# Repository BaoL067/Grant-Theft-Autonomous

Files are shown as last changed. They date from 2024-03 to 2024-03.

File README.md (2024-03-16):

# Grant Theft Autonomous 2023 
 This repository contains the source code for the annual competition of Design of Mechatronic Systems.

# TEAM 16, WE ARE THE CHAMPION !!!

# Video Link

- **Evaluation of functionality:** [**https://youtu.be/02jUuSZZPl0**](https://youtu.be/02jUuSZZPl0)

- **Final competition:** [**https://youtu.be/HylkRfzkrz0**](https://youtu.be/HylkRfzkrz0)

- **Compete Competition recording** at [GRASP Lab Youtube Channel.](https://www.youtube.com/watch?v=Pt5Qd4mry5I&t=9516s)



---



---

# Functionality

- Autonomous Wall Following
- Autonomous Beacon Tracking, Grasping Trophy
- Autonomous Navigate and Push the Police car
- Real-time positioning of XY location, and broadcasting via UDP
- Manual Wireless Control through Key-board

# Electrical Design

- ## Vive Localization System

  A single Vive chip can localize the position of robot, while two combined can determine the direction of it.

  ****

图片图片

- ## TOF Distance Measurement System

  Three TOF sensors are used in total, with two placed on the sides of the vehicle and one placed at the front.

  ****

  

- ## IR Beacon Tracking System

Two infrared sensors are placed at the front of the vehicle, each isolated with shading material, to increase detection range and enhance detection accuracy.

****

图片图片

- ## Motor Driver System

  

  

# BOM

| **Item** | **Quantities** | **Price** |
| --- | --- | --- |
| DC Motors | 2 | $68.0 |
| Wheels | 2 | $7.50 |
| ToF sensors | 6 | $17.0 |
| Claw | 1 | $18.0 |
| Lipo Battery | 1 | $17.5 |
| Wheel connectors | 2 | $3.75 |

# Reference Datasheet

- **Motor(CQRobot Ocean):** [**http://www.cqrobot.wiki/index.php/DC_Gearmotor_SKU:_CQR37D**](http://www.cqrobot.wiki/index.php/DC_Gearmotor_SKU:_CQR37D)
- **Motor Driver(L298N):**[**L298N-Motor-Driver-Datasheet.pdf (components101.com)**](https://components101.com/sites/default/files/component_datasheet/L298N-Motor-Driver-Datasheet.pdf)
- **TOF(VL53L0X):**[**Time-of-Flight ranging sensor (st.com)**](https://www.st.com/resource/en/datasheet/vl53l0x.pdf)
- **Gripper:** [**Amazon.com: Mechanical Claw BigClaw Robot Gripper (without Servo) : Toys & Games**](https://www.amazon.com/dp/B08YDH27YK?ref=ppx_yo2ov_dt_b_product_details&th=1)

- **Battery(4s Lipo):**[**Amazon.com: HRB 4S 3300mAh Lipo Battery 60C 14.8V RC Lipo Battery Pack with XT60 Plug for RC Airplane, RC Helicopter, RC Car, RC Truck, RC Boat (EC3/Deans/TR/Tamiya) : Toys & Games**](https://www.amazon.com/dp/B06XKWFPRZ?psc=1&ref=ppx_yo2ov_dt_b_product_details)

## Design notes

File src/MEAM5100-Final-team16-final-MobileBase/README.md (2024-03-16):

# MEAM5100-Final

## 这里可以找到 ESP32 支持的库

https://www.arduinolibraries.info/architectures/esp32

## Requirement

[ESP32Encoder by K.H.](https://www.arduino.cc/reference/en/libraries/esp32encoder/)
[文档](https://madhephaestus.github.io/ESP32Encoder/classESP32Encoder.html)

[L298N by A.L.](https://www.arduino.cc/reference/en/libraries/l298n/)
我更改了这个库叫做 L298N-ESP32，添加了 `setVelocity` method 更方便接受 PID 的输出。

[PID by B.B.](https://www.arduino.cc/reference/en/libraries/pid/)

## Debug

Encoder by P.S.
https://www.arduino.cc/reference/en/libraries/encoder/
这个库的中断写法不支持 ESP32，会导致一直 reboot。
这是因为 ESP32 上的中断会在前面加上 IRAM_ATTR（意思是把中断放在 IRAM 中，而不是在较慢的闪存中），是 ESP32 里特殊的写法。
在 include 前面加上 #define ENCODER_DO_NOT_USE_INTERRUPTS 能避免使用中断（用轮询）以解决这个问题，但 document 说这样会丢失精度。

issue 里提出的解决方案：
1 RLars fork 的库  
2 用 NewEncoder 库
https://github.com/gfvalvo/NewEncoder  
3 ESP32Encoder by K.H.  
https://www.arduino.cc/reference/en/libraries/esp32encoder/  
https://madhephaestus.github.io/ESP32Encoder/classESP32Encoder.html  
4 https://github.com/igorantolic/ai-esp32-rotary-encoder

我们最终选择了第三个方案（star 多）。初步测试正常。需要使用 attachFullQuad 模式，轮子转一圈会有 64\*210 个脉冲。

[L298N by A.L.](https://www.arduino.cc/reference/en/libraries/l298n/)
因为 analogWrite，好像也存在不支持 ESP32 的问题。
用 [ESP32_AnalogWrite](https://github.com/erropix/ESP32_AnalogWrite) 或者 [AnalogWrite_ESP32](https://github.com/pablomarquez76/AnalogWrite_ESP32) 能直接将 ESP32 的 PWM API 改成了和 arduino 一样。
但如[pablomarquez76](https://github.com/pablomarquez76/AnalogWrite_ESP32/issues/6)所言，ESP32 在 2.0.11 之后的新版本已经支持 analogWrite。官方文档[在这](https://docs.espressif.com/projects/arduino-esp32/en/latest/api/ledc.html?highlight=analogWrite#analogwrite)。resolution 为 0 到 255，在此范围内测试正常，没有试过超过这个值会怎么样。

team33 用 CPM 速度作为 PID 输入，ledc 14 bit PWM 作为 PID 输出，也就是范围是 0-55 输入，0-16382 输出，PID 参数取 400 50 3 能获得较好效果。输出是输入的 297.85 倍。
team16 用 m/s 速度作为 PID 输入，analogWrite 作为 PID 输出，也就是范围是 0-0.25 输入，0-255 输出，输出是输入的 1020 倍。那理论上取 3.42 倍的参数也能获得较好效果，即 1370 170 10。测试结果很好。

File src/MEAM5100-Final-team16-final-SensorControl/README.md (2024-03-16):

# MEAM5100-Final

## Requirement

[Adafruit_VL53L0X](https://www.arduino.cc/reference/en/libraries/adafruit_vl53l0x/)

[ESP32Servo by K.H.](https://www.arduino.cc/reference/en/libraries/esp32servo/)
[文档](https://madhephaestus.github.io/ESP32Servo/annotated.html)

## 代码逻辑

我会用另一块 ESP32 C3（暂且叫它 M 板）来给这块板（暂且叫它 C 板）发信息。

我希望给他发 WASD 前后左右 QE 方向微调 P 停车 的时候他直接传达给下层板，也就是手动控制模式。
然后会有三个模式，分别是 1 2 3。分别对应 wall following, move police, navigate to trophy。

wall following

如果正面 tof 小于某个值，a + delay

如果侧面前 tof 大于某个值，e

如果侧面前 tof 小于某个值，q

如果侧面前 tof 数据都在某个范围内（无论侧面后 tof 是怎么样的） w

move police

得到自己的位置，和朝向
得到 police 位置
转弯，w

走到 police 面前
转弯，w

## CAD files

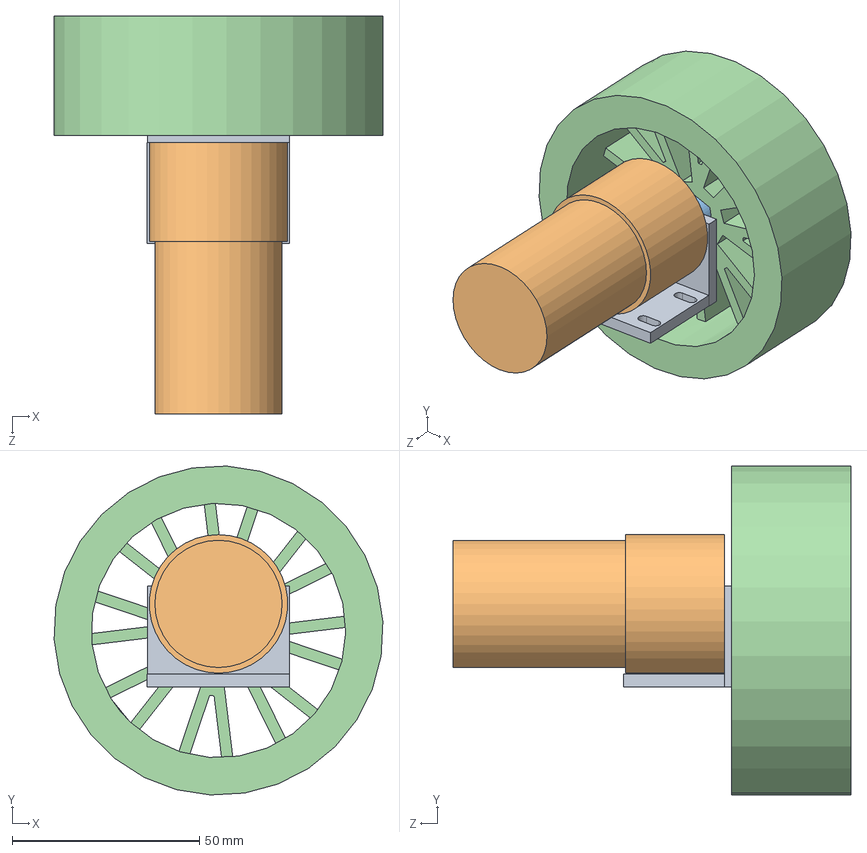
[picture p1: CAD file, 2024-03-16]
Model/电机-轮子直连.SLDASM
87.9 x 87.9 x 106.4 mm
DC_MountFinalProject
DC_FinalProject
DShaftAdaptor_FinalProject
Wheel

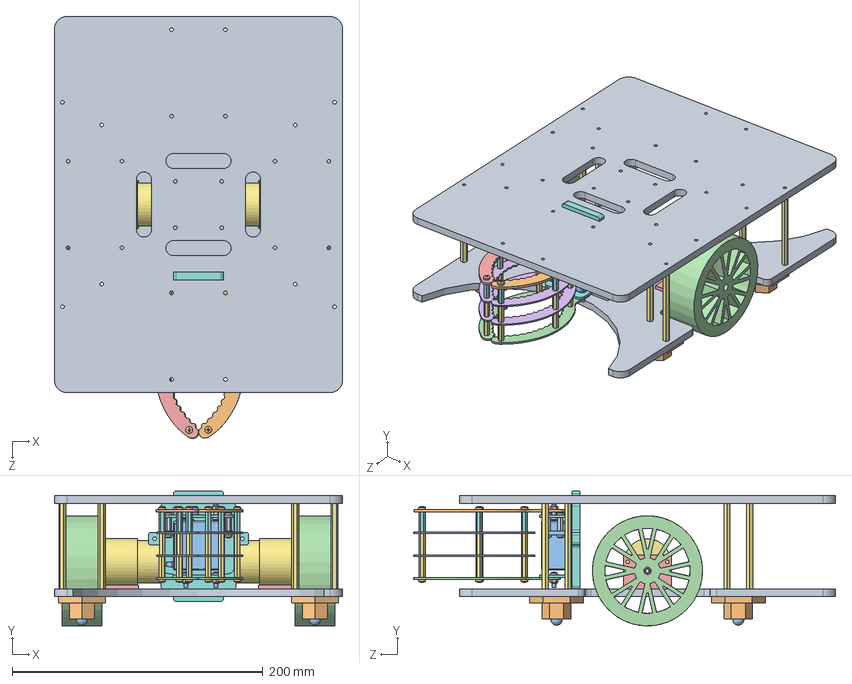
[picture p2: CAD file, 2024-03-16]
Model/Final_Robot.SLDASM
230.0 x 107.5 x 336.6 mm
Final Project底板
滚珠安装架 x 4
滚珠球 x 4
Wheel x 2
Motor Mount x 2
DShaftAdaptor_FinalProject x 2
DC_FinalProject x 2
支架1
M3X11双通铜柱 x 4
GB818-M3X6-ZN-4.8 x 21
GB818-M3X10-ZN-4.8 x 2
底部长支架 x 2
GB6170-M3（自锁） x 3
短支架 x 4
M3X17+6铜柱 x 12
M3X16双通铜柱 x 6
GB818-M3X12-ZN-4.8
左边长支架
小舵机
金属主舵盘
右边长支架
GB818-M3X5-ZN-4.8 x 2
erSupport x 8
Claw Board
Upper layer

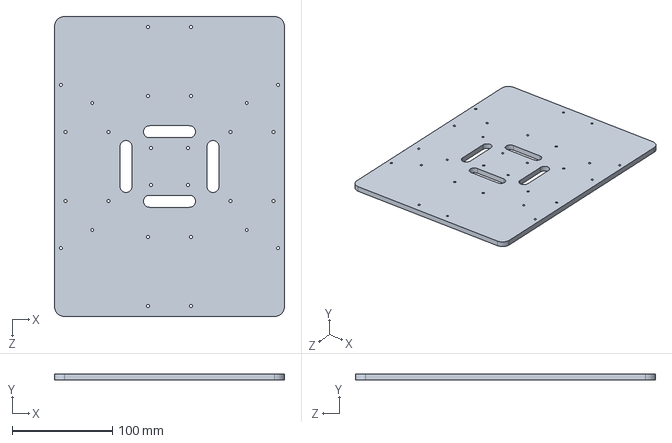
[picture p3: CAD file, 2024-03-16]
Model/Upper_layer.SLDPRT
230.0 x 6.35 x 300.0 mm

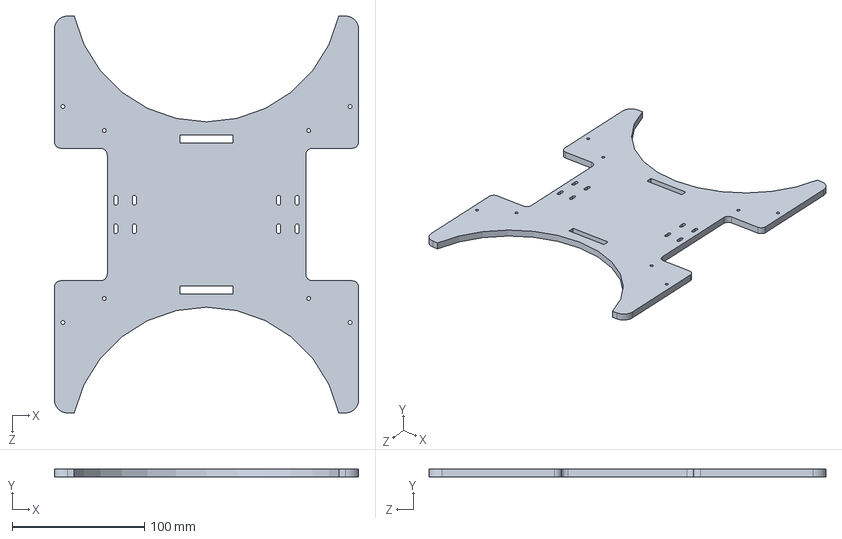
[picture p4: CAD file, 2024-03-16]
Model/Final_Project底板.SLDPRT
230.0 x 6.18 x 300.0 mm

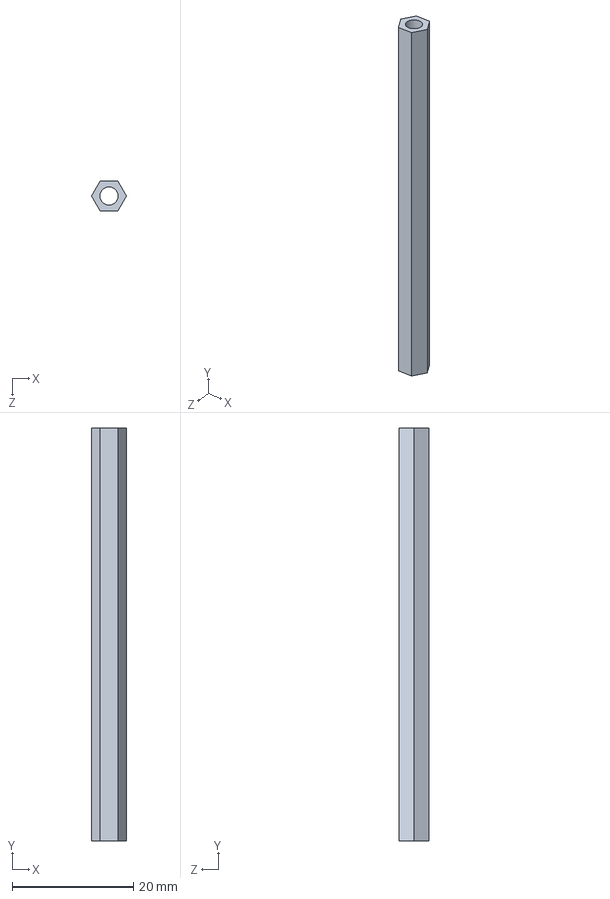
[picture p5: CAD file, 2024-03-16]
Model/erSupport.SLDPRT
5.77 x 68.0 x 5.00 mm

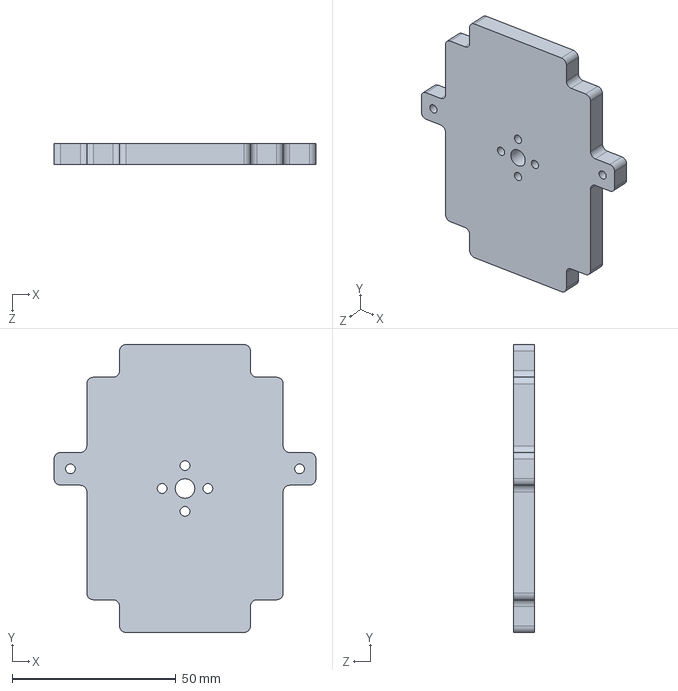
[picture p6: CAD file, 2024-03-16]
Model/Claw_Board.SLDPRT
80.0 x 88.0 x 6.35 mm

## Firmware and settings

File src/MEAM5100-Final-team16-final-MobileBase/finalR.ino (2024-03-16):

#include <PID_v1.h>
// This library is used to control the PID loop
#include <ESP32Encoder.h> 
// This library is used to read the encoder values
// #include <ESP32Servo.h>
// This library is used to control the servo motor
#include "L298N.h"
// This library is used to control the DC motor
#include <esp_now.h>
#include <WiFi.h>


// Define the pins for the servo motor
#define FRONT_SERVO_PIN 23
#define REAR_SERVO_PIN2 22

// Define the pins for the DC motors and encoders
#define LEFT_MOTOR_PWM_PIN 32
#define LEFT_MOTOR_DIR_PIN1 33
#define LEFT_MOTOR_DIR_PIN2 26

// pin 25 not work, we tested two ESP32 board
// unknown reason
#define RIGHT_MOTOR_DIR_PIN1 27
#define RIGHT_MOTOR_DIR_PIN2 14
#define RIGHT_MOTOR_PWM_PIN 12

#define LEFT_ENCODER_PIN1 36
#define LEFT_ENCODER_PIN2 39
#define RIGHT_ENCODER_PIN1 34
#define RIGHT_ENCODER_PIN2 35



// Motor Control ///////////////////////////////////////////////////////////////////
const int gearRatio = 210;
const int encoderCPR = 64;
const float wheelCircumference = 0.276;

L298N leftMotor(LEFT_MOTOR_PWM_PIN, LEFT_MOTOR_DIR_PIN1, LEFT_MOTOR_DIR_PIN2);
L298N rightMotor(RIGHT_MOTOR_PWM_PIN, RIGHT_MOTOR_DIR_PIN1, RIGHT_MOTOR_DIR_PIN2);

struct MotorState {
    ESP32Encoder encoder;
    int64_t lastEncoderCount = 0;
    unsigned long lastTime = 0;    
};

MotorState leftMotorState, rightMotorState;

double calculateSpeed(MotorState& motorState) {
    unsigned long currentTime = millis();
    double timeInterval = (currentTime - motorState.lastTime) / 1000.0; // in seconds

    int64_t currentEncoderCount = motorState.encoder.getCount();
    int64_t countDelta = currentEncoderCount - motorState.lastEncoderCount;

    double speed = (countDelta / (double)(encoderCPR * gearRatio)) * wheelCircumference / timeInterval;

    // update state
    motorState.lastEncoderCount = currentEncoderCount;
    motorState.lastTime = currentTime;

    return speed;
}

// Car Control ////////////////////////////////////////////////////////
volatile char direction;


// PID Control ////////////////////////////////////////////////////////

double Kp = 1370.0, Ki = 170.0, Kd = 10.0;
double leftSpeedInput, rightSpeedInput;
double leftPWMOutput, rightPWMOutput;
double setLeftSpeed = 0.0; 
double setRightSpeed = 0.0; 
double referenceSpeed = 0.0; // for debug only

PID leftMotorPID(&leftSpeedInput, &leftPWMOutput, &setLeftSpeed, Kp, Ki, Kd, DIRECT);
PID rightMotorPID(&rightSpeedInput, &rightPWMOutput, &setRightSpeed, Kp, Ki, Kd, DIRECT);

// ESPNOW //////////////////////////////////////////////////////

// R mac address: {0xD4,0xD4,0xDA,0x42,0x75,0x98}
// C mac address: {0xD8,0xBC,0x38,0xE5,0xC1,0xF4}
void OnDataRecv(const uint8_t *mac_addr, const uint8_t *data, int data_len) {
    Serial.printf(" Recv from: %02x:%02x:%02x:%02x:%02x:%02x ",mac_addr[0], mac_addr[1], mac_addr[2], mac_addr[3], mac_addr[4], mac_addr[5]); 
    Serial.print(" Data: "); 
    // if the first byte is a char, then it is a command
    if (isascii(data[0])) {
        Serial.println((char *)data);
        direction = data[0];
    } else {
        Serial.println("Not a command");
    }
}
///////////////////////////////////////////////////////////////

void setupESPNOW() {
    WiFi.mode(WIFI_STA);
    Serial.print("ESPNow Receiving MAC: ");  Serial.println(WiFi.macAddress());

    if (esp_now_init() != ESP_OK) {
        Serial.println("ESPNow Init Failed");
        ESP.restart();
    }
    esp_now_register_recv_cb(OnDataRecv);   
    Serial.println("ESP32 MAC Address: ");
    Serial.println(WiFi.macAddress());  // find my mac adress 
    delay(50);
}

void setupEncoder() {
    // attach the pins of the encoder to the ESP32
    leftMotorState.encoder.attachFullQuad(LEFT_ENCODER_PIN1, LEFT_ENCODER_PIN2);
    rightMotorState.encoder.attachFullQuad(RIGHT_ENCODER_PIN1, RIGHT_ENCODER_PIN2);
    // clear the encoder count
    leftMotorState.encoder.clearCount();
    rightMotorState.encoder.clearCount();
    Serial.println("Setup Encoder Done!");
    delay(50);
}

void setupMotor(){
    leftMotor.setVelocity(0); // 0-255
    rightMotor.setVelocity(0); // 0-255
    Serial.println("Setup Motor Done!");
    delay(50);
}

void setupPID(){
    leftMotorPID.SetMode(AUTOMATIC);
    rightMotorPID.SetMode(AUTOMATIC);
    leftMotorPID.SetOutputLimits(-255, 255);
    rightMotorPID.SetOutputLimits(-255, 255);
    leftMotorPID.SetSampleTime(50);
    rightMotorPID.SetSampleTime(50);
    Serial.println("Setup PID Done!");
    delay(50);
}

void setup() {
    Serial.begin(115200);
    setupPID();
    setupEncoder(); 
    setupMotor();
    setupESPNOW();
    Serial.println("Setup All Done!");
}

void loop() {

    switch (direction) {
    case 'w':          // forward
        setLeftSpeed = 0.24;
        setRightSpeed = 0.24;
        break;
    case 's':          // backward
        setLeftSpeed = -0.24;
        setRightSpeed = -0.24;
        break;

    case 'a':          // turn left
        setLeftSpeed = -0.2;
        setRightSpeed = 0.2;
        break;

    case 'd':          // turn right
        setLeftSpeed = 0.2;
        setRightSpeed = -0.2;
        break;

    case 'q':          // fine turn left
        setLeftSpeed = 0.15;
        setRightSpeed = 0.23;
        break;

    case 'e':          // fine turn right
        setLeftSpeed = 0.23;
        setRightSpeed = 0.15;
        break;

    case 'p':          // stop
        setLeftSpeed = 0;
        setRightSpeed = 0;
        break;
}


    leftSpeedInput = calculateSpeed(leftMotorState);
    rightSpeedInput = calculateSpeed(rightMotorState);
    
    Serial.printf("leftSpeedInput:%lf , rightSpeedInput:%lf \n", leftSpeedInput, rightSpeedInput);
    Serial.printf("referenceSpeed:%lf \n", referenceSpeed);
    // update PID
    leftMotorPID.Compute();
    rightMotorPID.Compute();

    // Serial.printf("leftPWMOutput:%lf , rightPWMOutput:%lf \n", leftPWMOutput, rightPWMOutput);

    // output PWM
    leftMotor.setVelocity(leftPWMOutput);
    rightMotor.setVelocity(rightPWMOutput);


    delay(30);
}

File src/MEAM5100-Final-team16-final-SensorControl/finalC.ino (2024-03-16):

#include <Arduino.h>
#include <esp_now.h>
#include <WiFi.h>
#include "TOF.h"

#define IR_PIN1 18
#define IR_PIN2 19
#define C_MAC  {0xD8,0xBC,0x38,0xE5,0xC1,0xF4} 
#define R_MAC  {0xD4,0xD4,0xDA,0x42,0x75,0x98} 
#define TA_MAC {0xC8,0xF0,0x9E,0xF6,0xE0,0xC8}  
#define M_MAC {0xA0,0x76,0x4E,0x19,0xC0,0x14}  
// C mac address is D8:BC:38:E5:C1:F4
// C is this borad
// R mac address is D4:D4:DA:42:75:98
// R is the mobile base
// M mac address is A0:76:4E:19:C0:14
// M is the main control board on computer
// TA mac address is C8:F0:9E:F6:E0:C8

#include "vive.h"
#define CHANNEL 1

#include <ESP32Servo.h>
#define SERVO_PIN 4
Servo myservo;
int pos = 0;

TOFSensorManager tofManager;
volatile char ModeStatus = '0';
volatile char GripperStatus = 'k';

esp_now_peer_info_t peerR = 
{
    .peer_addr = R_MAC, 
    .channel = CHANNEL,
    .encrypt = false,
};
esp_now_peer_info_t peerTA = 
{
    .peer_addr = TA_MAC, 
    .channel = CHANNEL,
    .encrypt = false,
};
esp_now_peer_info_t peerM = 
{
    .peer_addr = M_MAC, 
    .channel = CHANNEL,
    .encrypt = false,
};


// Usage: send_message('R', "w");
// To R board, send w
void send_message(char where, uint8_t key) {
    uint8_t message[] = {key};
    if (where == 'R'){
        esp_now_send(peerR.peer_addr, message, sizeof(message));
    }
    else if (where == 'T'){
        esp_now_send(peerTA.peer_addr, message, sizeof(message));
    }
    else if (where == 'M'){
        esp_now_send(peerM.peer_addr, message, sizeof(message));
    }
    delay(30); 
}
void send_message(char where, const char* message) {
    if (where == 'R'){
        esp_now_send(peerR.peer_addr, reinterpret_cast<const uint8_t*>(message), strlen(message));
    }
    else if (where == 'T'){
        esp_now_send(peerTA.peer_addr, reinterpret_cast<const uint8_t*>(message), strlen(message));
    }
    else if (where == 'M'){
        esp_now_send(peerM.peer_addr, reinterpret_cast<const uint8_t*>(message), strlen(message));
    }
    delay(30); 
}

// everytime we receive a message, we send it to M and TA board
void OnDataRecv(const uint8_t *mac_addr, const uint8_t *data, int data_len) { 

    String message = "Team16: I received a message from Main board: ";
    message += String(reinterpret_cast<const char*>(data), data_len);
    send_message('T', message.c_str());
    send_message('M', message.c_str());
    if(isValidGripper(data[0])){
        GripperStatus = data[0];
    }else{
        ModeStatus = data[0];
    }
}

void closeGripper(){
  for (pos = myservo.read(); pos <= 60; pos += 1) {
    myservo.write(pos);
    delay(15);
  }
  GripperStatus = 'k'; // keep
}

void openGripper(){
    for (pos = myservo.read(); pos >= 0; pos -= 1) {
        myservo.write(pos);
        delay(15);
    }
    GripperStatus = 'k'; // keep
}

void setupESPNOW() {
    WiFi.mode(WIFI_STA);  
    Serial.print("MAC address: ");  Serial.println(WiFi.macAddress());

    if (esp_now_init() != ESP_OK) {
        Serial.println("init failed");
        ESP.restart();
    }
    esp_now_register_recv_cb(OnDataRecv);  
    if (esp_now_add_peer(&peerR) != ESP_OK) {
        Serial.println("Pair failed with R");     // ERROR  should not happen
    }
    if (esp_now_add_peer(&peerTA) != ESP_OK) {
        Serial.println("Pair failed with TA");     // ERROR  should not happen
    }
    if (esp_now_add_peer(&peerM) != ESP_OK) {
        Serial.println("Pair failed with M");     // ERROR  should not happen
    }
}



/////////////////////////////////////////////////////////
// wasdqe for movement, zc for rotation, p for stop
const char validKeys[] = {'w', 'a', 's', 'd', 'q', 'e', 'p', 'z', 'c'};
// different modes
const char validMode[] = {'1', '2', '3'};
// o for open, l for close
const char validGripper[] = {'o', 'l'};

bool isValidKey(char key) {
    for (int i = 0; i < sizeof(validKeys) / sizeof(validKeys[0]); i++) {
        if (key == validKeys[i]) {
            return true;
        }
    }
    return false;
}

bool isValidGripper(char key) {
    return (key == 'o' || key == 'l' || key=='k');
}

/////////////////////////////////////////////////////////
int trophyCount = 0;

void setup() {
    Serial.begin(115200);
    // setupUDP(); // wifi channel problem
    setupVive(); 
    setupESPNOW();
    tofManager.initializeSensors();
    pinMode(IR_PIN1, INPUT);
    pinMode(IR_PIN2, INPUT);
    myservo.attach(SERVO_PIN, 500, 2500);
}

void loop() {
    static uint32_t lastPrintTime = millis();
    static uint32_t lastSendTime = millis();
    
    // get vive data
    uint16_t frontX = 0;
    uint16_t frontY = 0;
    uint16_t rearX = 0;
    uint16_t rearY = 0;
    getViveData(frontX, frontY, vive1);
    getViveData(rearX, rearY, vive2);
    uint16_t centerX = frontX;
    uint16_t centerY = frontY;
    float angle = calcAngle(frontX, frontY, rearX, rearY);
    // map to percentage
    int centerPercX = (centerX - X_MIN)/((float)X_MAX - X_MIN)*100.0;
    int centerPercY = (centerY - Y_MIN)/((float)Y_MAX - Y_MIN)*100.0;
    // get tof data
    int d1 = tofManager.readSensor(1);
    int d2 = tofManager.readSensor(2);
    int d3 = tofManager.readSensor(3);
    // get IR data
    // no need to get IR data, just use digitalRead(IR_PIN1) and digitalRead(IR_PIN2)
    


    // every second, send 5 times vive, tof, IR data to M
    if (millis() - lastPrintTime > 200) {
        lastPrintTime = millis();
        Serial.println("I am running");

        String ViveMessage = "x: " + String(centerPercX) + " y: " + String(centerPercY) + " angle: " + String(angle) + "\n";
        String TOFMessage = "d1: " + String(d1) + " d2: " + String(d2) + " d3: " + String(d3) + "\n";
        String IRMessage = "IR1: " + String(digitalRead(IR_PIN1)) + " IR2: " + String(digitalRead(IR_PIN2)) + "\n";
        String SensorMessage = ViveMessage  + TOFMessage + IRMessage;
        send_message('M', SensorMessage.c_str());
    }
    
    delay(20);


    // gripper control
    if(isValidGripper(GripperStatus)){
        if (GripperStatus == 'l') {            
            Serial.println("Increasing servo position");
            closeGripper();
        } else if (GripperStatus == 'o') {
            Serial.println("Decreasing servo position");
            openGripper();
        }else {
            myservo.write(pos);
        }
    }

    // movement control
    if (isValidKey(ModeStatus)) {
        send_message('R', ModeStatus);
        if (millis() - lastSendTime > 1000) {
            lastSendTime = millis();
            String CommandMessage = "Send to R : ";
            CommandMessage += ModeStatus;
            send_message('M', CommandMessage.c_str());
        }
    }

    else if (ModeStatus == '1') {  // auto mode
        // wall following
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
